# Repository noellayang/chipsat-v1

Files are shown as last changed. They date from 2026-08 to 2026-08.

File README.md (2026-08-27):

# ChipSat v1: Solar-Powered CubeSat Power Testbed

ChipSat v1 is a custom 45mm x 45mm PCB I built to test how firmware power-management decisions affect the actual current draw of a small satellite-style system. It was developed alongside my power budget work for the Duke Solar Sail project.

<p align="center">
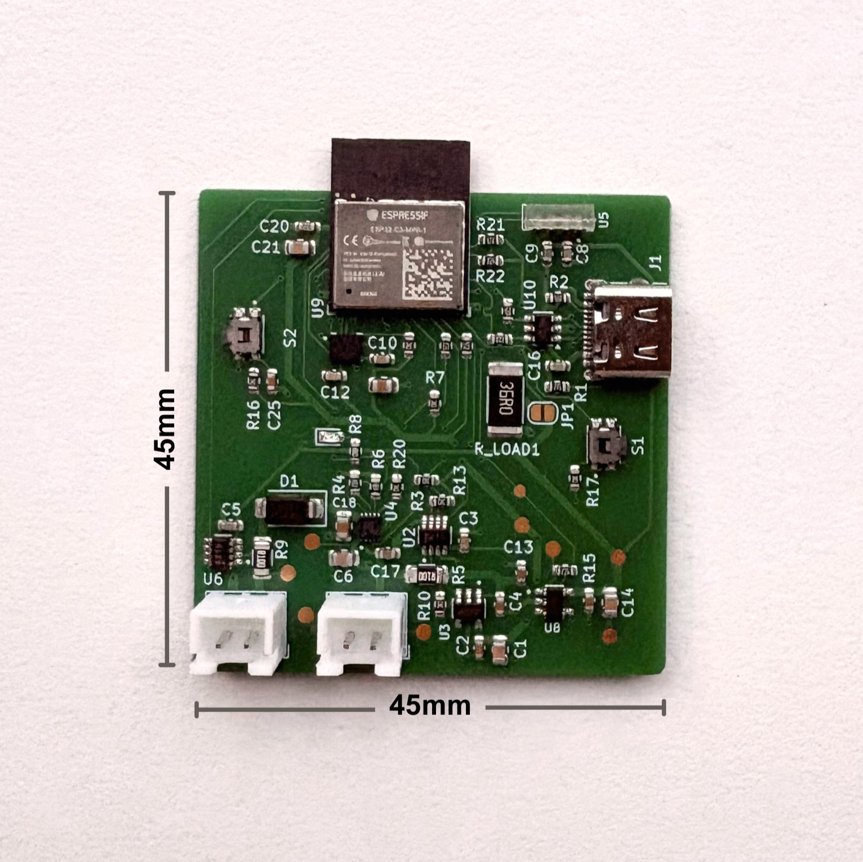
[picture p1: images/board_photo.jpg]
Assembled ChipSat v1 board, 45mm x 45mm
  
</p>

## What this is

The goal was not to reproduce flight hardware exactly. Instead, I wanted a physical testbed where I could keep the hardware fixed and measure how much the power draw changed as I switched between different firmware schedules.

The board includes:

* ESP32-C3-MINI-1 MCU with native USB
* Solar input and Li-ion charging using the BQ25185
* Two INA219 current and voltage monitors: one on the solar input and one on the main system rail
* ICM-42688-P 6-axis IMU over SPI
* VEML7700 ambient light sensor
* Switchable `+3V3_SENS` rail for the sensor domain
* 36Ω switched load behind a solder jumper to emulate an approximately 300mW ADCS load, comparable to a single magnetorquer actuation
* BLE telemetry using the ESP32-C3 radio as a stand-in for LoRa downlink. I kept the same 780ms transmission window and cadence used in the mission power model (and without attempting to reproduce LoRa RF behavior)

## Repo layout

```text
hardware/         KiCad project: schematic, PCB layout, design rules
manufacturing/    Gerbers, drill files, pick-and-place, fab submission files
images/           Board photos and test figures
docs/             BOM
```

## Firmware power states

| State | MCU | IMU | +3V3_SENS | BLE proxy | Mission interpretation |
| --- | --- | --- | --- | --- | --- |
| Eclipse sleep | Deep sleep between events | Off | Off | Wake every 30s, advertise for 0.78s | Earth-shadow stress case with nominal telemetry retained |
| Housekeeping  | Active | Off | Off | 0.78s every 30s | Scheduling and health checks |
| Full sensing  | Active | On  | On | 0.78s every 30s | Complete sensing window |

## Results

### Power-state testing

Deep sleep reduced average current by 95.4%.

Each state was run over a representative 30s cycle:

* Eclipse sleep: 2.25mA
* Housekeeping: 48.59 ± 0.10mA
* Full sensing: 50.14 ± 0.11mA

I also tested the switched 36Ω load used to emulate an ADCS event. System current increased from a 26.02mA baseline to 118.48 ± 0.87mA with the load enabled, close to the expected result for an approximately 300mW resistive load.

<p align="center">
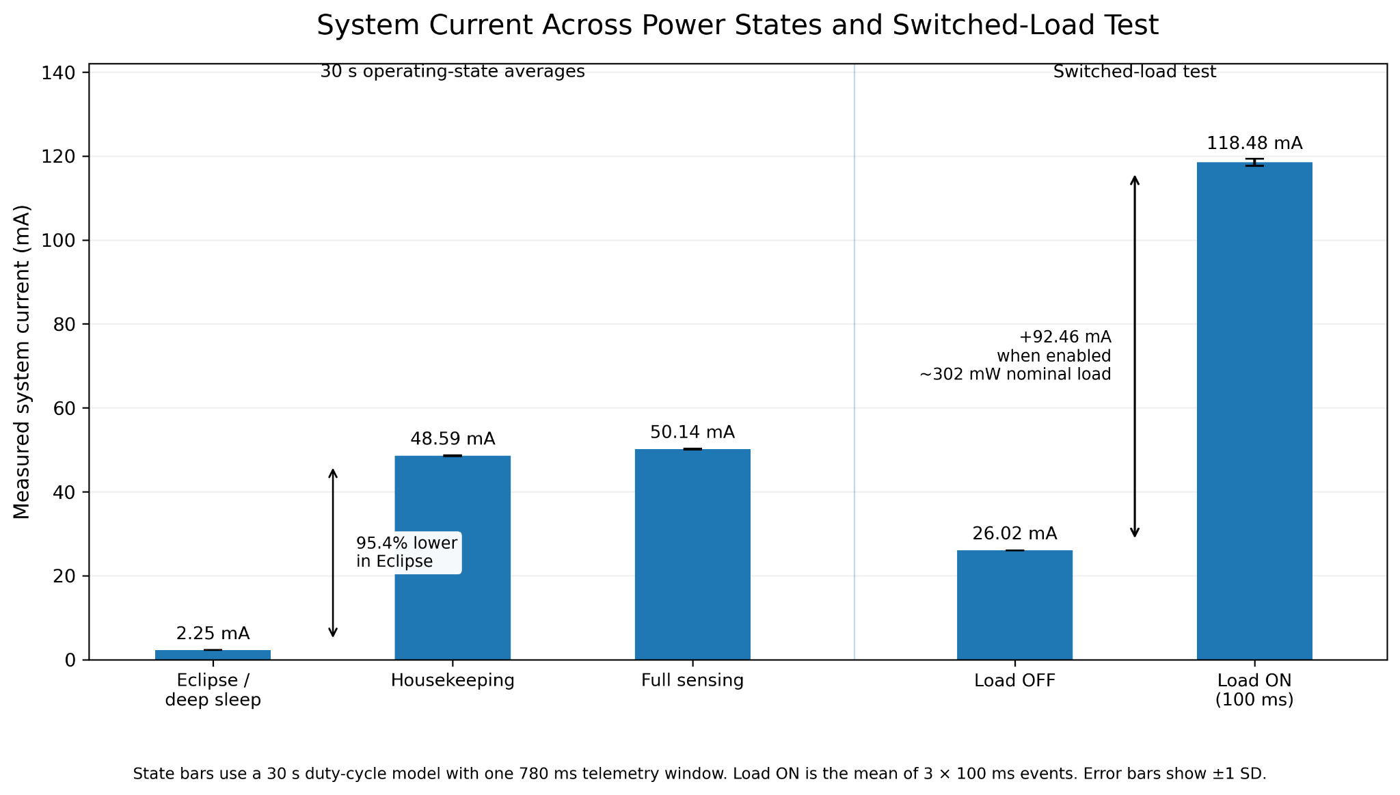
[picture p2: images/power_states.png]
System current across power states and switched-load test
  
</p>

### BLE telemetry

I held the board in Full Sensing for 60s and enabled BLE advertising for 780ms every 30s.

Across three trials, the baseline stayed at 53.67 ± 0.10mA. During the advertising windows, the INA219 measured short peaks up to 121.5mA.

At this cadence, the radio is active for roughly 2.6% of the cycle. The test helped confirm that the BLE event appears as a short current spike rather than setting the power draw for the full operating period.

<p align="center">
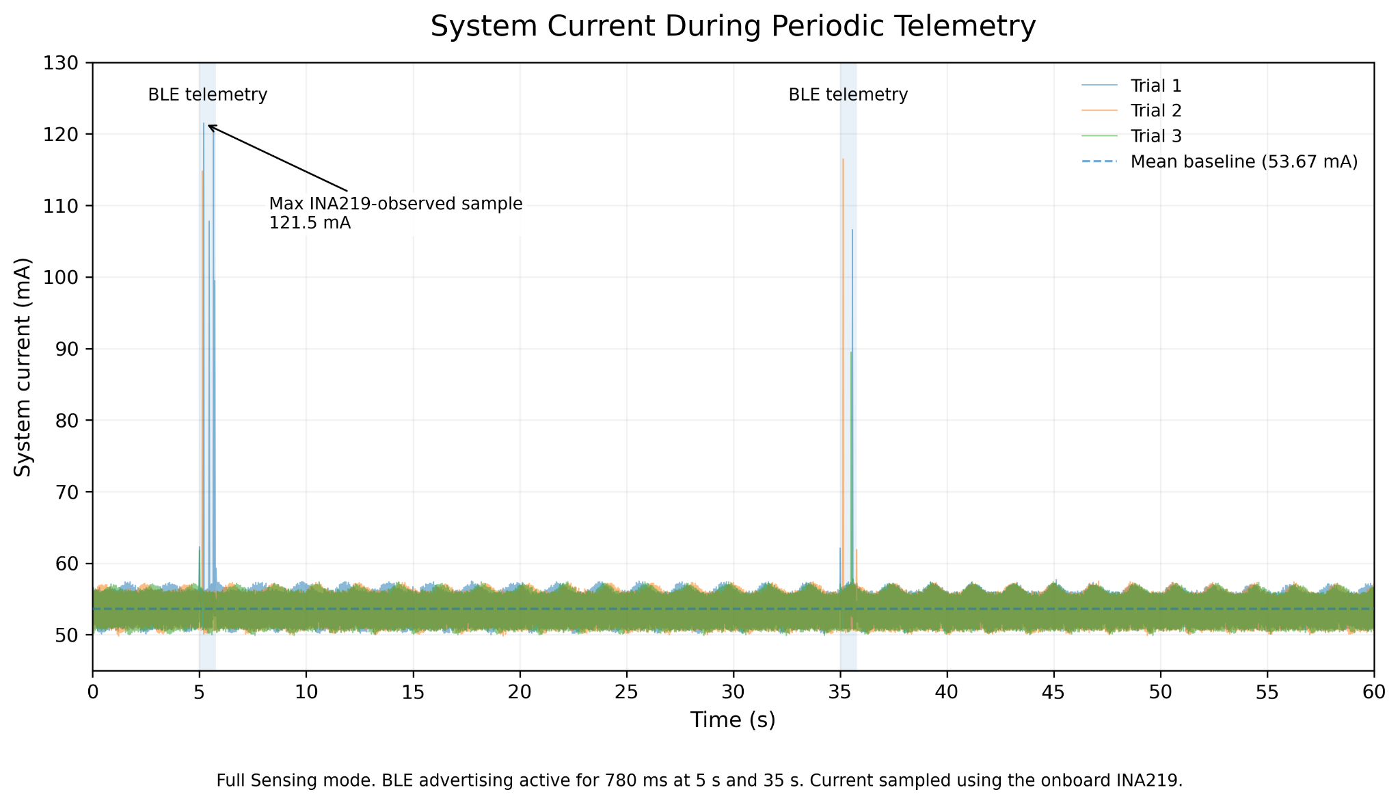
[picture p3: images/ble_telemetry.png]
System current during periodic BLE telemetry
  
</p>

### Solar harvesting

I used the solar-side INA219 together with the VEML7700 to compare harvested power against measured illuminance.

Harvested power increased from 3.01 ± 0.68mW at about 1669 lux to 16.77 ± 0.91mW at about 2669 lux.

The lowest-light measurement is close to the practical measurement floor of the INA219 with the 0.1Ω shunt, so that point has noticeably more variation than the higher-light measurements.

<p align="center">
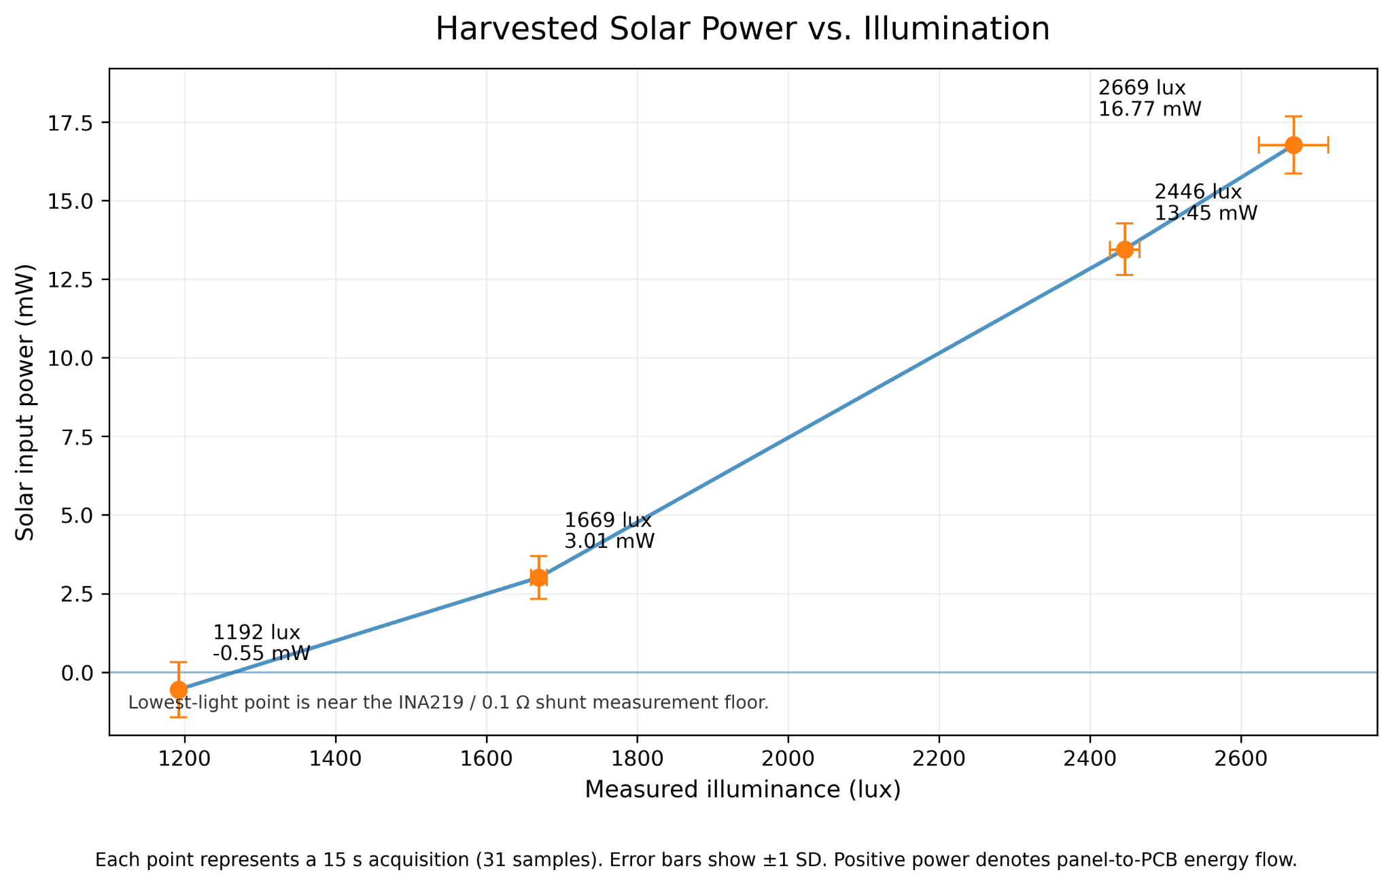
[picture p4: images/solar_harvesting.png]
Harvested solar power vs illuminance
  
</p>

## Bring-up notes

A few issues from bring-up ended up being especially useful:

### I2C bus switching

The ESP32-C3 only has one I2C controller, while the board uses two physical I2C buses. Firmware therefore remaps the controller depending on which bus is being accessed.

One issue appeared when I disabled the sensor rail before an I2C transaction had fully completed. This could leave SDA or SCL in the wrong state and break later communication. I fixed it by completing the transaction and releasing the bus before switching off `+3V3_SENS`.

### Low-current measurement floor

Under weak illumination, the solar current became small enough that the INA219 and 0.1Ω shunt were operating near their useful measurement limit. At that point, offset and resolution were large enough for the reported current to occasionally drift around zero.

I kept the data rather than filtering it out, but marked the lowest-light point as being close to the measurement floor.

### BLE stack overhead

One result I did not initially expect was the cost of simply initializing BLE.

Even with advertising disabled, bringing up the BLE stack raised the active current noticeably. Because of this, "advertising off" and "BLE fully deinitialized" are separate power states in the firmware rather than being treated as equivalent.

## Manufacturing

Gerbers, drill files, and the original fab submission files for the 2-layer PCB are included in [`manufacturing/`](manufacturing/).

The KiCad project is the source of truth. If you need outputs for a different board house, regenerate them from:

`hardware/chipsat_v1.kicad_pcb`

## BOM

The full bill of materials, including LCSC part numbers, is available at [`docs/BOM.csv`](docs/BOM.csv).

## Opening the project

KiCad 8 or newer is recommended.

Open:

`hardware/chipsat_v1.kicad_pro`

## License

MIT. See [LICENSE](LICENSE).

The hardware design files are included for reference and reuse. If you build directly on the board design, credit back to this repo is appreciated.

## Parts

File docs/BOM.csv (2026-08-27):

Designator | Qty | Comment | Footprint | LCSC Part # | Manufacturer | Manufacturer Part Number
C1,C6,C14,C21 | 4 | 10µF | Capacitor_SMD:C_0805_2012Metric | C17024 | Samsung Electro-Mechanics | CL21A106KPFNNNE
C2,C4,C9,C13,C15,C17,C25 | 7 | 1µF | Capacitor_SMD:C_0603_1608Metric | C26413 | Samsung Electro-Mechanics | CL10A105KP8NNNC
C3,C5,C8,C10,C16,C20 | 6 | 100nF | Capacitor_SMD:C_0603_1608Metric | C1591 | Samsung Electro-Mechanics | CL10B104KB8NNNC
C11,C18 | 2 | 2.2µF | Capacitor_SMD:C_0805_2012Metric | C7282443 | Murata Electronics | GRM219R61A225KA01D
C12 | 1 | 10nF | Capacitor_SMD:C_0603_1608Metric | C1589 | Samsung Electro-Mechanics | CL10B103KB8NNNC
D1 | 1 | SS14 | Diode_SMD:D_SMA | C2480 | MDD(Microdiode Semiconductor) | SS14
D2 | 1 | LED | LED_SMD:LED_0603_1608Metric | C2286 | Hubei KENTO Elec | KT-0603R
J1 | 1 | USB-C | 12402012E212A:AMPHENOL_12402012E212A | C5150972 | Amphenol ICC | 12402012E212A
J4,J5 | 2 | Conn_01x02 | Connector_JST:JST_XH_B2B-XH-A_1x02_P2.50mm_Vertical | C19272845 | JST | B2B-XH-A
R1,R2 | 2 | 5.1k | Resistor_SMD:R_0603_1608Metric | C23186 | UNI-ROYAL(Uniroyal Elec) | 0603WAF5101T5E
R3,R7,R10,R13,R14,R16,R17,R20 | 8 | 10k | Resistor_SMD:R_0603_1608Metric | C25804 | UNI-ROYAL(Uniroyal Elec) | 0603WAF1002T5E
R4 | 1 | 3k | Resistor_SMD:R_0603_1608Metric | C4211 | UNI-ROYAL(Uniroyal Elec) | 0603WAF3001T5E
R5,R9 | 2 | 0.1R | Resistor_SMD:R_1206_3216Metric | C46961734 | jieerrui | RE1206F1R100
R6 | 1 | 18k | Resistor_SMD:R_0603_1608Metric | C25810 | UNI-ROYAL(Uniroyal Elec) | 0603WAF1802T5E
R8 | 1 | 1K | Resistor_SMD:R_0603_1608Metric | C22548 | YAGEO | RC0603FR-071KL
R11,R12,R21,R22 | 4 | 4.7K | Resistor_SMD:R_0603_1608Metric | C23162 | UNI-ROYAL(Uniroyal Elec) | 0603WAF4701T5E
R15 | 1 | 47k | Resistor_SMD:R_0603_1608Metric | C25819 | UNI-ROYAL(Uniroyal Elec) | 0603WAF4702T5E
R18,R19 | 2 | 22R | Resistor_SMD:R_0603_1608Metric | C23345 | UNI-ROYAL(Uniroyal Elec) | 0603WAF220JT5E
R_LOAD1 | 1 | 36R | Resistor_SMD:R_2512_6332Metric | C190228 | UNI-ROYAL(Uniroyal Elec) | 25121WF360JT4E
S1,S2 | 2 | EVQ-P7A01P | EVQ-P7A01P:SW_EVQ-P7A01P | C79167 | PANASONIC | EVQP7A01P
U2,U6 | 2 | INA219AIDCNR | INA219AIDCNR:SOT65P280X145-8N | C87469 | Texas Instruments | INA219AIDCNR
U3,U8 | 2 | AP2112K-3.3TRG1 | AP2112K-3.3TRG1:SOT95P285X140-5N | C51118 | Diodes Inc. | AP2112K-3.3TRG1
U4 | 1 | BQ25185DLHR | BQ25185DLHR:IC_BQ25185DLHR | C19725033 | Texas Instruments | BQ25185DLHR
U5 | 1 | VEML7700-TR | VEML7700-TR:XDCR_VEML7700-TR | C504893 | Vishay Intertech | VEML7700-TR
U7 | 1 | ICM-42688-P | ICM-42688-P:PQFN50P300X250X97-14N | C1850418 | TDK InvenSense | ICM-42688-P
U9 | 1 | ESP32-C3-MINI-1 | PCM_Espressif:ESP32-C3-MINI-1 | C2838502 | Espressif Systems | ESP32-C3-MINI-1-N4
U10 | 1 | USBLC6-2SC6 | Package_TO_SOT_SMD:SOT-23-6 | C7519 | STMicroelectronics | USBLC6-2SC6

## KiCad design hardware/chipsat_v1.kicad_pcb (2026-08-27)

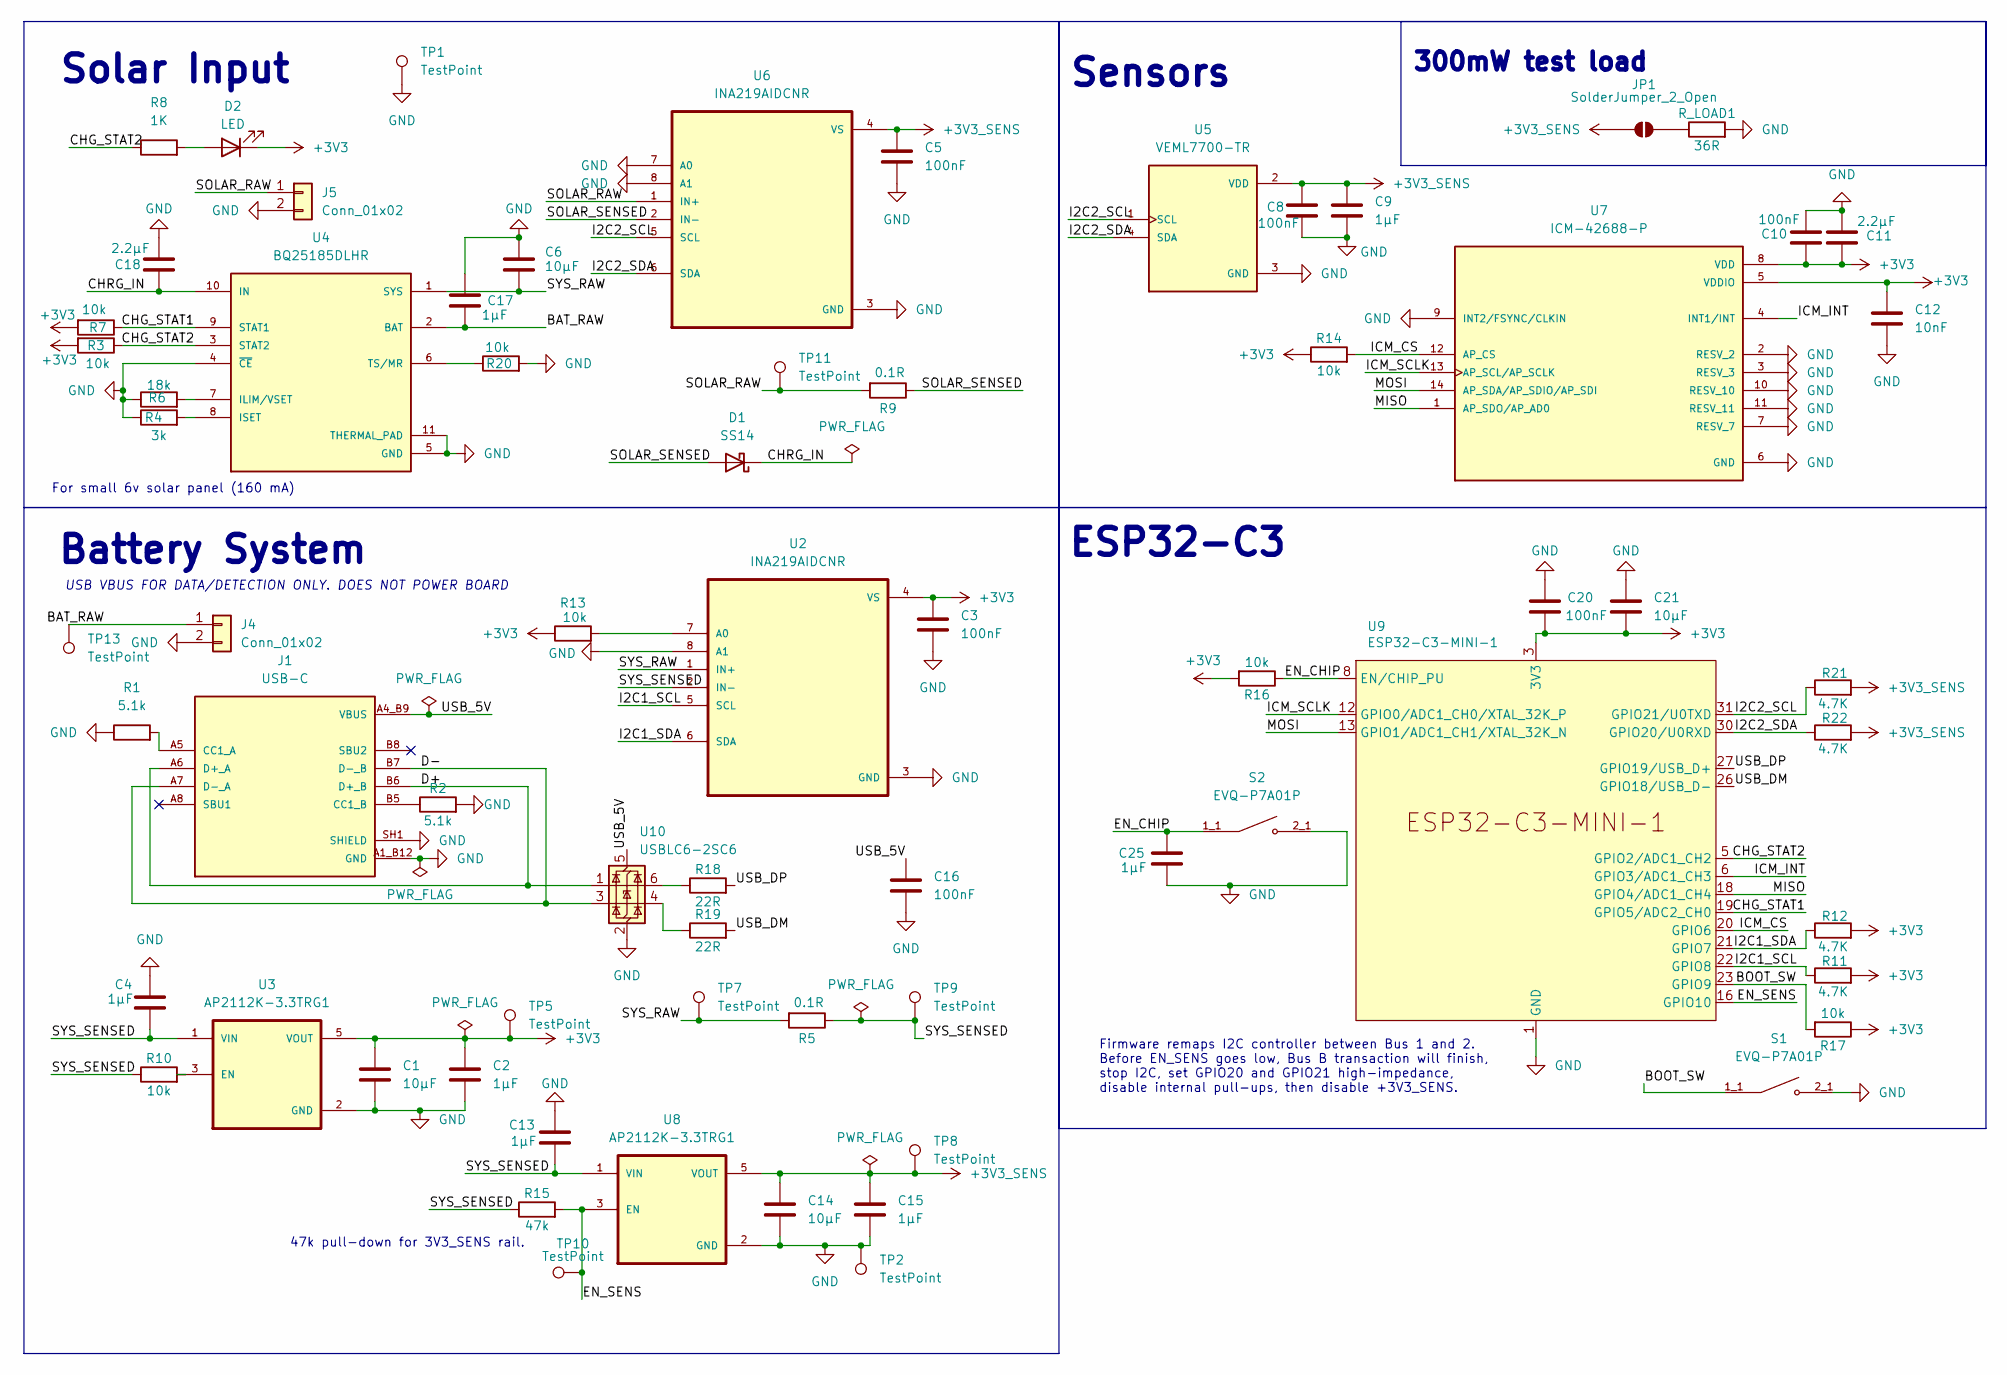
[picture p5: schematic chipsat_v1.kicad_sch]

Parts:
C1, C6, C14, C21: 10µF; C_0805_2012Metric; Manufacturer Part Number CL21A106KPFNNNE; LCSC Part # C17024
C2, C4, C9, C13, C15, C17, C25: 1µF; C_0603_1608Metric; Manufacturer Part Number CL10A105KP8NNNC; LCSC Part # C26413
C3, C5, C8, C10, C16, C20: 100nF; C_0603_1608Metric; Manufacturer Part Number CL10B104KB8NNNC; LCSC Part # C1591
C11, C18: 2.2µF; C_0805_2012Metric; Manufacturer Part Number CL21A225KPFNNNE; LCSC Part # C84716
C12: 10nF; C_0603_1608Metric; Manufacturer Part Number CL10B103KB8NNNC; LCSC Part # C1589
D1: SS14; D_SMA; Manufacturer Part Number SS14; LCSC Part # C2480
D2: LED; LED_0603_1608Metric; Manufacturer Part Number KT-0603R; LCSC Part # C2286
J1: USB-C; AMPHENOL_12402012E212A; PARTREV 4; LCSC Part # C5150972
J4, J5: Conn_01x02; JST_XH_B2B-XH-A_1x02_P2.50mm_Vertical; Manufacturer Part Number B2B-XH-A(LF)(SN); LCSC Part # C158012
JP1: SolderJumper_2_Open; SolderJumper-2_P1.3mm_Open_RoundedPad1.0x1.5mm
R1, R2: 5.1k; R_0603_1608Metric; Manufacturer Part Number 0603WAF5101T5E; LCSC Part # C23186
R3, R7, R10, R13, R14, R16, R17, R20: 10k; R_0603_1608Metric; Manufacturer Part Number 0603WAF1002T5E; LCSC Part # C25804
R4: 3k; R_0603_1608Metric; Manufacturer Part Number 0603WAF3001T5E; LCSC Part # C4211
R5, R9: 0.1R; R_1206_3216Metric; Manufacturer Part Number RE1206F1R100; LCSC Part # C46961734
R6: 18k; R_0603_1608Metric; Manufacturer Part Number 0603WAF1802T5E; LCSC Part # C25810
R8: 1K; R_0603_1608Metric; Manufacturer Part Number RC0603FR-071KL; LCSC Part # C22548
R11, R12, R21, R22: 4.7K; R_0603_1608Metric; Manufacturer Part Number 0603WAF4701T5E; LCSC Part # C23162
R15: 47k; R_0603_1608Metric; Manufacturer Part Number 0603WAF4702T5E; LCSC Part # C25819
R18, R19: 22R; R_0603_1608Metric; Manufacturer Part Number 0603WAF220JT5E; LCSC Part # C23345
R_LOAD1: 36R; R_2512_6332Metric; Manufacturer Part Number 25121WF360JT4E; LCSC Part # C190228
S1, S2: EVQ-P7A01P; SW_EVQ-P7A01P; PARTREV 2022.4; LCSC Part # C79167
TP1, TP2, TP5, TP7, TP8, TP9, TP11, TP13: TestPoint; TP_SMD_Round_1.5mm
TP10: TestPoint; TP_SMD_Round_1.2mm
U2, U6: INA219AIDCNR; SOT65P280X145-8N; Manufacturer Part Number INA219AIDCNR; LCSC Part # C87469
U3, U8: AP2112K-3.3TRG1; SOT95P285X140-5N; PARTREV 2-2; LCSC Part # C51118
U4: BQ25185DLHR; IC_BQ25185DLHR; PARTREV OCTOBER 2023; LCSC Part # C19725033
U5: VEML7700-TR; XDCR_VEML7700-TR; PARTREV 1.6; LCSC Part # C504893
U7: ICM-42688-P; PQFN50P300X250X97-14N; PARTREV 1.2; LCSC Part # C1850418
U9: ESP32-C3-MINI-1; Manufacturer Part Number ESP32-C3-MINI-1-N4; LCSC Part # C2838502
U10: USBLC6-2SC6; SOT-23-6; Manufacturer Part Number USBLC6-2SC6; LCSC Part # C7519

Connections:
+3V3: C1.1, C2.2, C3.1, C10.1, C11.1, C12.1, C20.2, C21.2, D2.1 (K), R3.2, R7.2, R11.2, R12.2, R13.1, R14.1, R16.2, R17.1, TP5.1 (1_1), U2.4 (VS), U3.5 (VOUT), U7.5 (VDDIO), U7.8 (VDD), U9.3 (3V3)
+3V3_SENS: C5.1, C8.2, C9.2, C14.2, C15.2, JP1.1 (A), R21.2, R22.2, TP8.1 (1_1), U5.2 (VDD), U6.4 (VS), U8.5 (VOUT)
/BAT_RAW: C17.1, J4.1, TP13.1 (1_1), U4.2 (BAT)
/BOOT_SW: R17.2, S1.1_1, S1.1_2, U9.23 (GPIO9)
/CHG_STAT1: R7.1, U4.9 (STAT1), U9.19 (GPIO5/ADC2_CH0)
/CHG_STAT2: R3.1, R8.1, U4.3 (STAT2), U9.5 (GPIO2/ADC1_CH2)
/CHRG_IN: C18.1, D1.1 (K), U4.10 (IN)
/D+: J1.A6 (D+_A), J1.B6 (D+_B), U10.1 (I/O1)
/D-: J1.A7 (D-_A), J1.B7 (D-_B), U10.3 (I/O2)
/EN_CHIP: C25.2, R16.1, S2.1_1, S2.1_2, U9.8 (EN/CHIP_PU)
/EN_SENS: R15.2, TP10.1 (1_1), U8.3 (EN), U9.16 (GPIO10)
/I2C1_SCL: R11.1, U2.5 (SCL), U9.22 (GPIO8)
/I2C1_SDA: R12.1, U2.6 (SDA), U9.21 (GPIO7)
/I2C2_SCL: R21.1, U5.1 (SCL), U6.5 (SCL), U9.31 (GPIO21/U0TXD)
/I2C2_SDA: R22.1, U5.4 (SDA), U6.6 (SDA), U9.30 (GPIO20/U0RXD)
/ICM_CS: R14.2, U7.12 (AP_CS), U9.20 (GPIO6)
/ICM_INT: U7.4 (INT1/INT), U9.6 (GPIO3/ADC1_CH3)
/ICM_SCLK: U7.13 (AP_SCL/AP_SCLK), U9.12 (GPIO0/ADC1_CH0/XTAL_32K_P)
/MISO: U7.1 (AP_SDO/AP_AD0), U9.18 (GPIO4/ADC1_CH4)
/MOSI: U7.14 (AP_SDA/AP_SDIO/AP_SDI), U9.13 (GPIO1/ADC1_CH1/XTAL_32K_N)
/SOLAR_RAW: J5.1, R9.2, TP11.1 (1_1), U6.1 (IN+)
/SOLAR_SENSED: D1.2 (A), R9.1, U6.2 (IN-)
/SYS_RAW: C6.2, R5.2, TP7.1 (1_1), U2.1 (IN+), U4.1 (SYS)
/SYS_SENSED: C4.1, C13.1, R5.1, R10.1, R15.1, TP9.1 (1_1), U2.2 (IN-), U3.1 (VIN), U8.1 (VIN)
/USB_DM: R19.2, U9.26 (GPIO18/USB_D-)
/USB_DP: R18.2, U9.27 (GPIO19/USB_D+)
GND: C1.2, C2.1, C3.2, C4.2, C5.2, C6.1, C8.1, C9.1, C10.2, C11.2, C12.2, C13.2, C14.1, C15.1, C16.1, C17.2, C18.2, C20.1, C21.1, C25.1, J1.A1_B12 (GND), J1.B1_A12 (GND), J1.SH1 (SHIELD), J1.SH2 (SHIELD), J1.SH3 (SHIELD), J1.SH4 (SHIELD), J4.2, J5.2, R1.1, R2.2, R4.1, R6.1, R20.2, R_LOAD1.2, S1.2_1, S1.2_2, S2.2_1, S2.2_2, TP1.1 (1_1), TP2.1 (1_1), U2.3 (GND), U2.8 (A1), U3.2 (GND), U4.4 (~CE), U4.5 (GND), U4.11 (THERMAL_PAD), U5.3 (GND), U6.3 (GND), U6.7 (A0), U6.8 (A1), U7.2 (RESV_2), U7.3 (RESV_3), U7.6 (GND), U7.7 (RESV_7), U7.9 (INT2/FSYNC/CLKIN), U7.10 (RESV_10), U7.11 (RESV_11), U8.2 (GND), U9.1 (GND), U9.2 (GND), U9.11 (GND), U9.14 (GND), U9.36 (GND), U9.37 (GND), U9.38 (GND), U9.39 (GND), U9.40 (GND), U9.41 (GND), U9.42 (GND), U9.43 (GND), U9.44 (GND), U9.45 (GND), U9.46 (GND), U9.47 (GND), U9.48 (GND), U9.49 (GND), U9.50 (GND), U9.51 (GND), U9.52 (GND), U9.53 (GND), U10.2 (GND)
unnamed: D2.2 (A), R8.2
unnamed: J1.A5 (CC1_A), R1.2
unnamed: J1.B5 (CC1_B), R2.1
unnamed: JP1.2 (B), R_LOAD1.1
unnamed: R18.1, U10.6 (I/O1)
unnamed: R19.1, U10.4 (I/O2)
unnamed: R13.2, U2.7 (A0)
unnamed: R10.2, U3.3 (EN)
unnamed: R6.2, U4.7 (ILIM/VSET)
unnamed: R4.2, U4.8 (ISET)
unnamed: R20.1, U4.6 (TS/MR)
VBUS: C16.2, J1.A4_B9 (VBUS), J1.B4_A9 (VBUS), U10.5 (VBUS)

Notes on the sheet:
ESP32-C3
47k pull-down for 3V3_SENS rail.
Firmware remaps I2C controller between Bus 1 and 2. Before EN_SENS goes low, Bus B transaction will finish, stop I2C, set GPIO20 and GPIO21 high-impedance, disable internal pull-ups, then disable +3V3_SENS.
USB VBUS FOR DATA/DETECTION ONLY. DOES NOT POWER BOARD
300mW test load
Battery System
Solar Input
For small 6v solar panel (160 mA)
Sensors

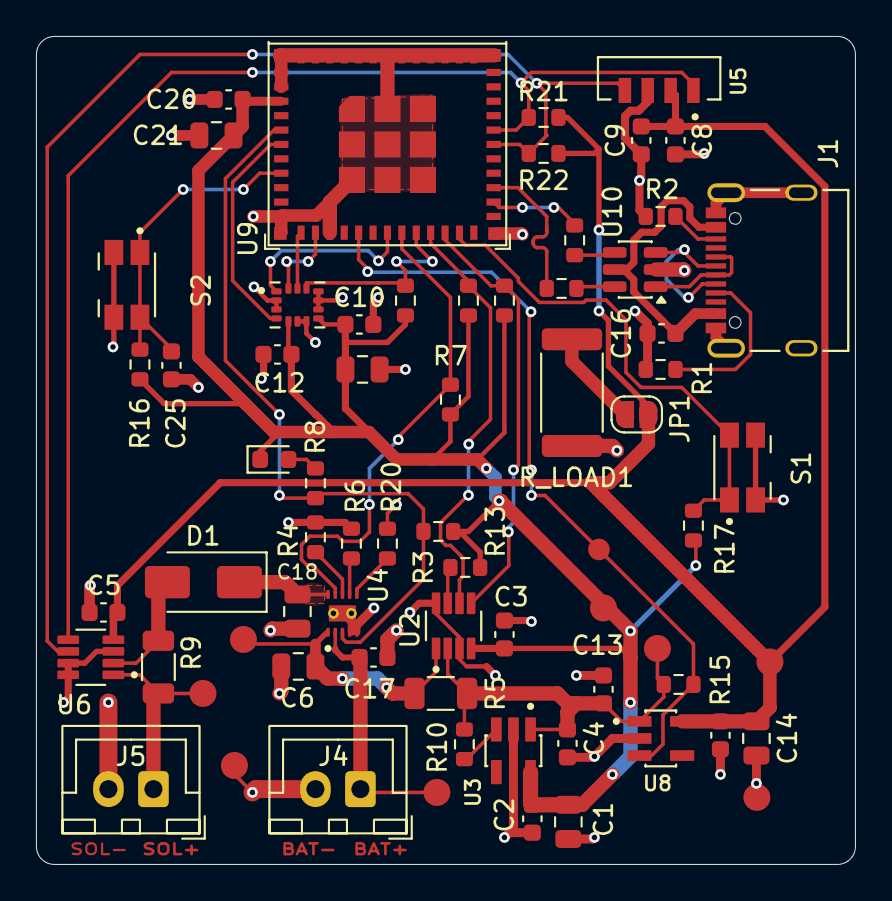
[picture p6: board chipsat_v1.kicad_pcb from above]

Board: 2 copper layers, 45.5 x 46.0 mm, 69 parts (0 on the bottom side), 39 nets.

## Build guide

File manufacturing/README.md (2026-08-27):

# Manufacturing outputs

- `fab_outputs/` — gerbers, drill files, silkscreen, solder mask, and V-cut data exported for fabrication.
- `fab_archives/` — the zipped fab-house submission packages, kept as-is for reference.

The KiCad project in `../hardware/` is the source of truth. Regenerate these from
`hardware/chipsat_v1.kicad_pcb` (Plot > Gerbers, then Generate Drill Files in KiCad)
if you need a different panelization or a different fab house's naming convention.
